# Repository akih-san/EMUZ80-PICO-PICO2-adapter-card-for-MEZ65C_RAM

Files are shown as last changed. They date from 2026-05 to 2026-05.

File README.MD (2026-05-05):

# EMUZ80 PICO/PICO2 adapter card for MEZ65C_RAM

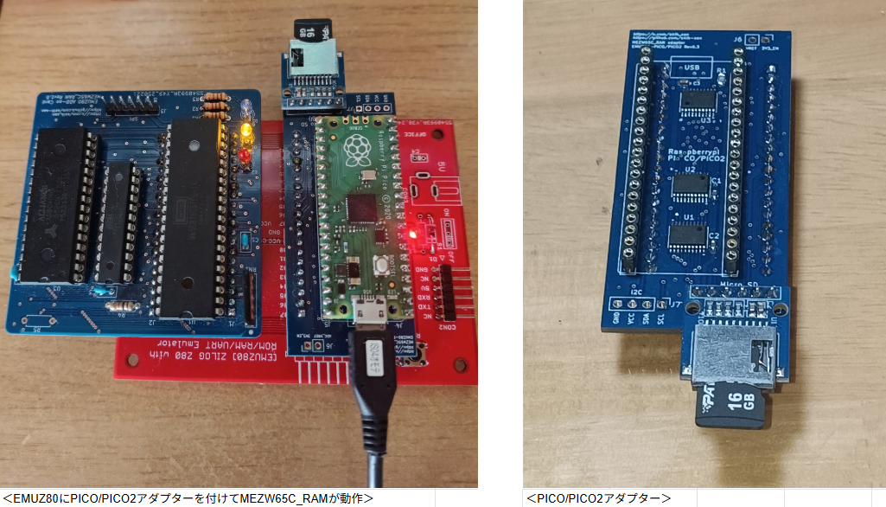
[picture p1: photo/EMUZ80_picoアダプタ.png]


電脳伝説さんの[EMUZ80](https://vintagechips.wordpress.com/2022/03/05/emuz80_reference)は、レガシーCPUをmicrochip社のPIC18F47Q43/83/84マイコンで制御しています。<br>
このマイクロコントローラーを[Raspberry Pi PICO/PICO2](https://www.raspberrypi.com/products/raspberry-pi-pico/)に置き換えて、動かせないかと考えていました。<br>
PICO/PICO2のIO数（GPIO)は、PIC18F47Q43/83/84に比べてかなり少ないため、個々のレガシーCPU専用のアダプターにする必要があります。<br>
私のお気に入りのレガシーCPUは6502なので（Z80も好きです）
[MEZW65C_RAM](https://github.com/akih-san/MEZW65C_RAM-Rev2.1G)用のアダプターを試作してみました。<br>

試作経緯については、[Ｘ（旧ツイッター）](https://x.com/akih_san/status/2036215330545213747)にアップしていますので、興味のある方はご覧ください。<br>

- [回路図](pdf/pico_pico2_to_emuz80_sch.pdf)
- [GPIO割り当て](pdf/pico_mezw65cGPIO割り当て.pdf)
- [部品表](pdf/pico_mezw65c部品表.pdf)<br>

<br>

- 電源は、USBから取るので、EMUZ80の電源は使用しない。電源回路を生かしている場合は、電源SWはOFFのままで使用すること。
- EMUZ80上のリセットSWは有効です。
- EMUZ80上のUART端子は有効ですが、PICO/PICO2のファームウェアで未対応。使用する場合は、PICOでUARTを有効にしてファームウェアを
再構築する必要があります。
- アダプタ上のI2C端子は、ファームウェア未対応です。

# 参考
FWを作成するときに、参考にしたサイトや書籍<br>

- [RP2350B EMU board](https://github.com/akih-san/RP2350B-EMU-BOARD-MEZW65C_RAM-Firmware)
- [MEZW65C_RAM-Rev2.1G](https://github.com/akih-san/MEZW65C_RAM-Rev2.1G)
- [MEZW65C_RAM-Rev2.0](https://github.com/akih-san/MEZW65C_RAM-Rev2.0)
- [MEZW65C_RAM-Rev2.1](https://github.com/akih-san/MEZW65C_RAM-Rev2.1)
- [Raspberry pi pico/pico2 The C/C++ SDK](https://www.raspberrypi.com/documentation/microcontrollers/c_sdk.html)
- [Ｃ言語を使った高精度な組み込みシステム　ラズパイPicoベアメタル開発完全ガイド](https://www.amazon.co.jp/%EF%BC%A3%E8%A8%80%E8%AA%9E%E3%82%92%E4%BD%BF%E3%81%A3%E3%81%9F%E9%AB%98%E7%B2%BE%E5%BA%A6%E3%81%AA%E7%B5%84%E3%81%BF%E8%BE%BC%E3%81%BF%E3%8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)
- PIOつくし（準備号）「Norihiro Kumagai氏](https://github.com/tendai22)
- [ちょっとTea　Time!? PICO repeating_timerの憂鬱【備忘録】](http://www.easyaudiokit.com/bekkan2025/TeaTime2025/pico_repeating_timer/timernewpage2.html)
- [Raspberry Pi Pico C/C++ インターバルタイマ割り込みを試してみる](https://qiita.com/keyyum/items/3ce448c098c546dced20)
- [Raspberry Pi PicoでPWM出力](https://rikei-tawamure.com/entry/2021/02/08/213335)
- [5V系・3.3V系信号レベル変換](https://www.cepstrum.co.jp/hobby/5v33v/5v33v.html)
- [FatFs library for Raspberry Pi Pico / Pico 2](https://github.com/elehobica/pico_fatfs)

# 謝辞
このボードを作成するに至った経緯は、[DragonBallEZ氏](https://github.com/kyo-ta04/)の[Super AKI-80の組み立て方](https://note.com/quiet_duck4046/n/n32906e1dfb96?sub_rt=share_sb)と、[Pico2ROMEmu_PCB](https://github.com/kyo-ta04/Pico2ROMEmu_PCB)がきっかけで、Raspberry pi pico/pico2に興味が湧いたことからはじまります。<br>
[Norihiro Kumagai氏](https://github.com/tendai22)の[emuz80_pico2](https://github.com/tendai22/emuz80_pico2)は非常に参考になりました。<br>
### 参考にしたサイトと共に、とても感謝しています。

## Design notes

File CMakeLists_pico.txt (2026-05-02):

# Generated Cmake Pico project file

cmake_minimum_required(VERSION 3.13)

set(CMAKE_C_STANDARD 11)
set(CMAKE_CXX_STANDARD 17)
set(CMAKE_EXPORT_COMPILE_COMMANDS ON)

# Initialise pico_sdk from installed location
# (note this can come from environment, CMake cache etc)

# == DO NOT EDIT THE FOLLOWING LINES for the Raspberry Pi Pico VS Code Extension to work ==
if(WIN32)
    set(USERHOME $ENV{USERPROFILE})
else()
    set(USERHOME $ENV{HOME})
endif()
set(sdkVersion 2.2.0)
set(toolchainVersion 14_2_Rel1)
set(picotoolVersion 2.2.0-a4)
set(picoVscode ${USERHOME}/.pico-sdk/cmake/pico-vscode.cmake)
if (EXISTS ${picoVscode})
    include(${picoVscode})
endif()
# ====================================================================================
set(PICO_BOARD pico CACHE STRING "Board type")

# Pull in Raspberry Pi Pico SDK (must be before project)
include(pico_sdk_import.cmake)

project(pico_mezw65c C CXX ASM)

add_compile_options(-O0)

# Initialise the Raspberry Pi Pico SDK
pico_sdk_init()

# Add executable. Default name is the project name, version 0.1

add_executable(pico_mezw65c pico_mezw65c.c
		io_dos.c
        fatfs/ff.c
        iodev/iodev.c
        iodev/cpu_ctl.c
        iodev/mem_ctl.c
        iodev/spi_sd.c
        iodev/pio_dev.c
        iodev/urt_dev.c
        iodev/i2c_dev.c
)

pico_set_program_name(pico_mezw65c "pico_mezw65c")
pico_set_program_version(pico_mezw65c "0.1")

# Generate PIO header
pico_generate_pio_header(pico_mezw65c ${CMAKE_CURRENT_LIST_DIR}/w65_irq.pio)

# Modify the below lines to enable/disable output over UART/USB
pico_enable_stdio_uart(pico_mezw65c 0)
pico_enable_stdio_usb(pico_mezw65c 1)

# Add the standard library to the build
target_link_libraries(pico_mezw65c
        pico_stdlib)

# Add the standard include files to the build
target_include_directories(pico_mezw65c PRIVATE
        ${CMAKE_CURRENT_LIST_DIR}
        ${CMAKE_CURRENT_SOURCE_DIR}/fatfs/
        ${CMAKE_CURRENT_SOURCE_DIR}/iodev/include/
)

# Add any user requested libraries
target_link_libraries(pico_mezw65c 
        hardware_spi
        hardware_i2c
        hardware_pio
        hardware_pwm
        )

pico_add_extra_outputs(pico_mezw65c)

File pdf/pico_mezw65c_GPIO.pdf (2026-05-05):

＜MEZW65C_RAM GPIO割り当て＞
GPIO | 名前 | PIC | ピン | GPIO | 名前 | PIC | ピン
GP0 | D0/BR0 | RB0 | J3-8, U2-2 | GP24 | - | - | -
GP1 | D1/BR1 | RB1 | J3-7,U2-3 | GP25 | LED（※） | - | at poco board
GP2 | D2/BR2 | RB2 | J3-6,U2-4 | GP26 | CLK | RA3 | J2-5
GP3 | D3/BR3 | RB3 | J3-5,U2-5 | GP27 | R/W | RA4 | J2-6
GP4 | D4/BR4 | RB4 | J3-4,U2-6 | GP28 | RDY | RA5 | J2-7
GP5 | D5/BR5 | RB5 | J3-3,U2-7 | | RUN | RE3 | J2-1
GP6 | D6/BR6 | RB6 | J3-2,U2-8 | | AL0 | RC0 | U2-19,J2-15
GP7 | D7/BR7 | RB7 | J3-1,U2-9 | | AL1 | RC1 | U2-18,J2-16
GP8 | RES | RE0 | J2-8 | | AL2 | RC2 | U2-17,J2-17
GP9 | NMI | RE1 | J2-9 | | AL3 | RC3 | U2-16,J2-18
GP10 | FF_CK | - | U1/U2-11 | | AL4 | RC4 | U2-15,J3-18
GP11 | FF_OE | - | U1/U2-1 | | AL5 | RC5 | U2-14,J3-17
GP12 | UART TX | RA6 | J2-14 | | AL6 | RC6 | U2-13,J3-16
GP13 | UART RX | RA7 | J2-13 | | AL7 | RC7 | U2-12,J3-15
GP14 | SDA | - | J7-2 | | AM0 | RD0 | U1-19,J2-19
GP15 | SCL | - | J7-1 | | AM1 | RD1 | U1-18,J2-20
GP16 | MISO | - | J1-2 | | AM2 | RD2 | U1-17,J3-20
GP17 | SPI_CS | - | J1-5 | | AM3 | RD3 | U1-16,J3-19
GP18 | SPI_CK | - | J1-3 | | AM4 | RD4 | U1-15,J3-14
GP19 | MOSI | - | J1-4 | | AM5 | RD5 | U1-14,J3-13
GP20 | BE | RA0 | J2-2 | | AM6 | RD6 | U1-13,J3-12
GP21 | DCK | RA1 | J2-3 | | AM7 | RD5 | U1-12,J3-11
GP22 | IRQ | RA2 | J2-4 | | SPI_SS | RE2 | J2-10,+5V
GP23 | - | - | -
※ GP25のLEDは、SDカードアクセス時に点滅

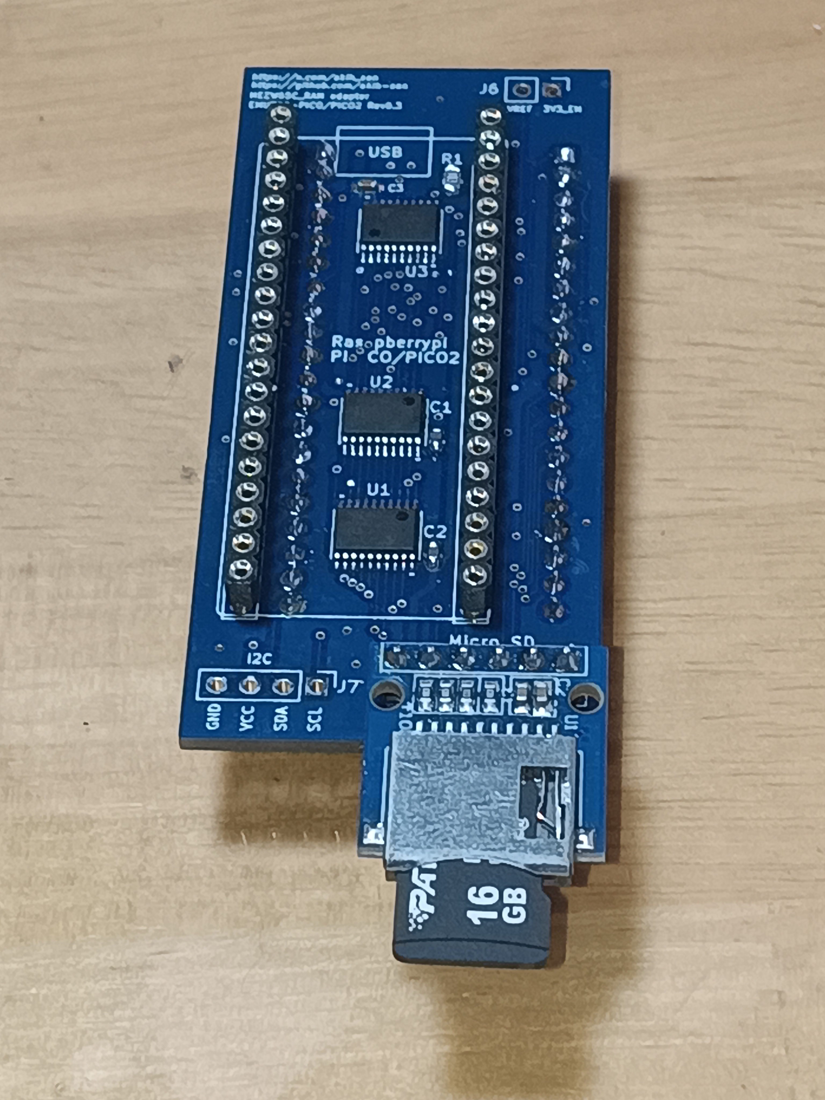
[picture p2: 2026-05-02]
photo/emuz80_pico_adapter.jpg

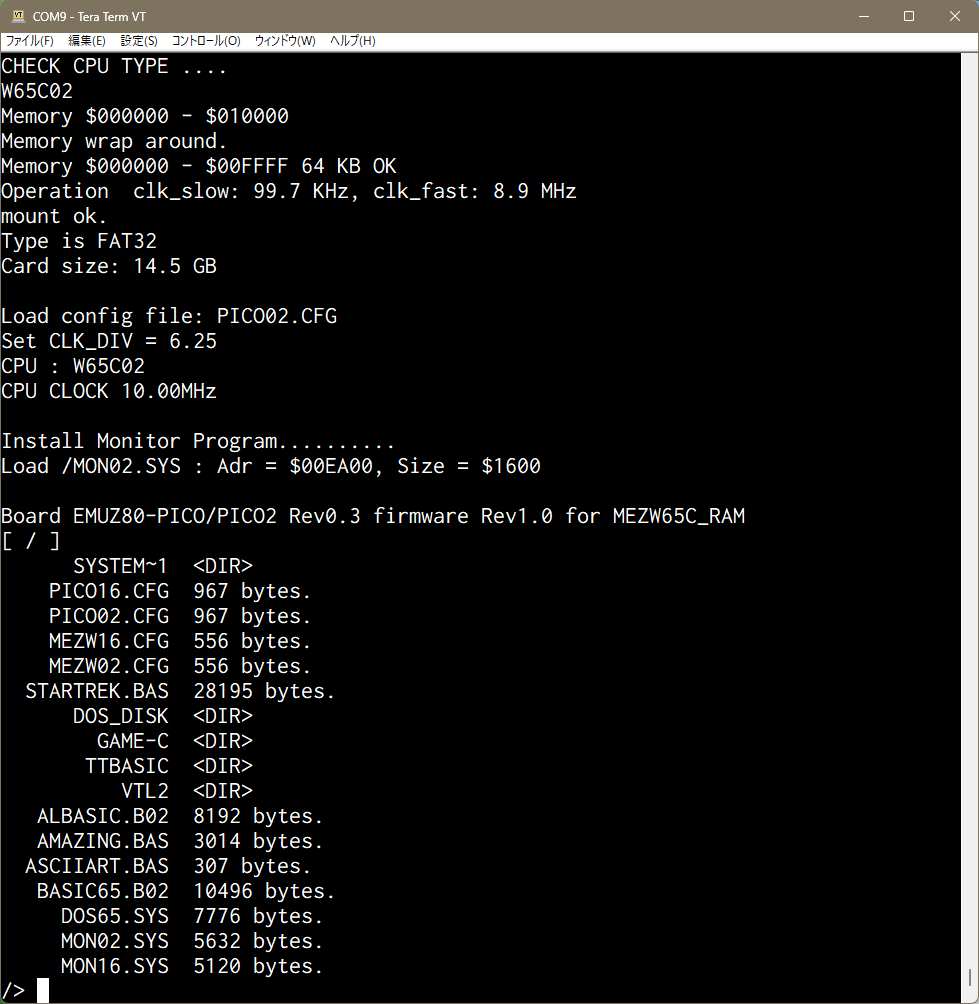
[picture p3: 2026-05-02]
photo/w65c02_opening.png

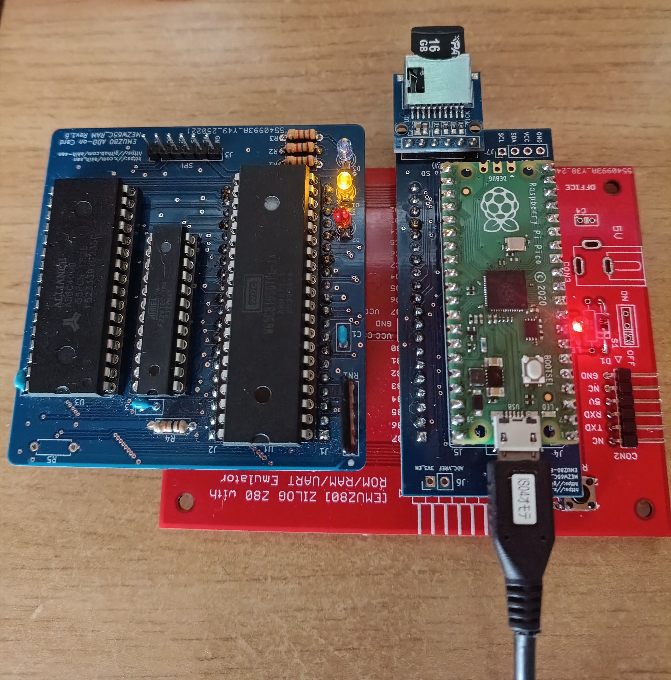
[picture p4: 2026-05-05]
photo/EMUZ80_PICO_PICO2_MEZ65C_RAM.jpg

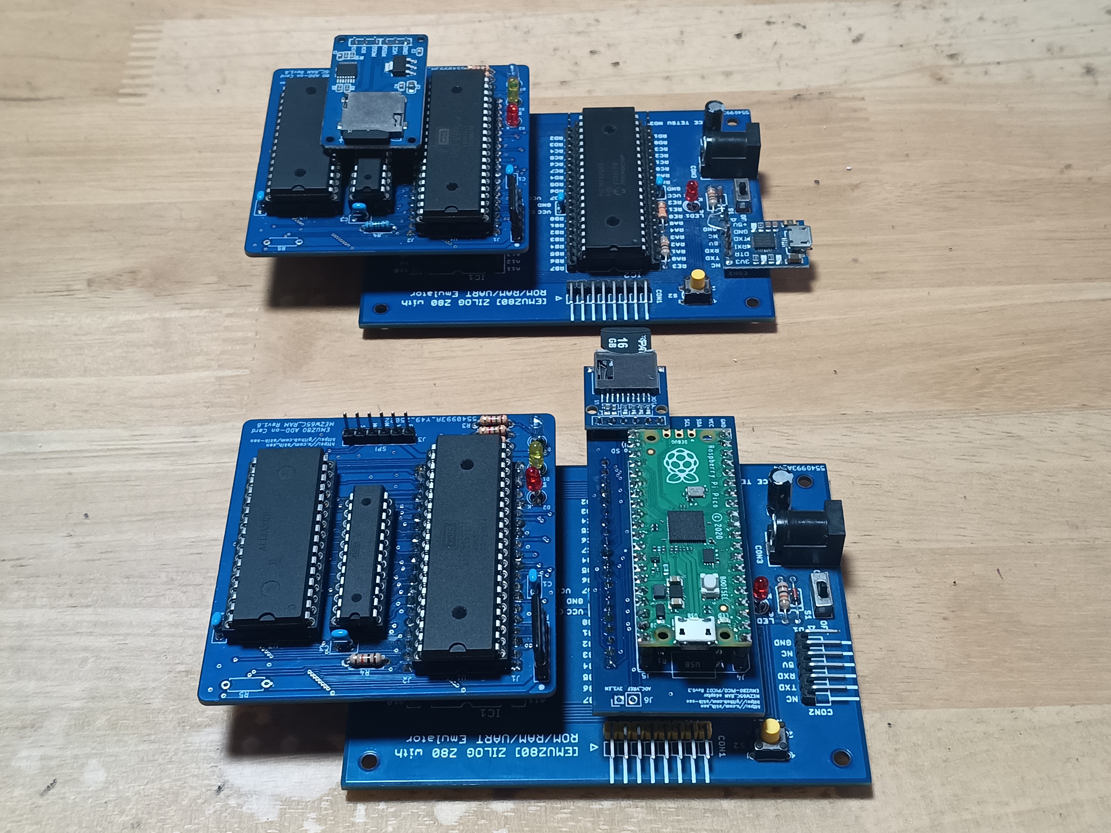
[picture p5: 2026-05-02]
photo/pico_adapter_and_PIC18F47Q43.jpg

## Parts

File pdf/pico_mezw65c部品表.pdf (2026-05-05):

MEZW65C_RAM PICO/PICO2アダプター部品表

部品番号 | 数 | 部品名 | 値 | 参考型番
C1,C2,C3 | 3 | チップ積層セラミックコンデンサー F 1608 | 0.1μF50V | GRM188F11H104ZA01（秋月電子通商）
J1 | 1 | SPI用 ピンヘッダー 1x06 2.54mm | | PH-1x6SG/RH（秋月電子通商）
J2,J3 | 2 | ピンソケット (メス) (シングル20P) 1x20 2.54mm | | FH-1x20（秋月電子通商）
JJ4,J5 | 2 | 丸ピンIC用ソケット (シングル20P) 1×20 2.54mm | | 6604S-20（秋月電子通商）
J6 | 1 | ピンヘッダー 1×2 (2P) | | PH-1X2SG（秋月電子通商）
J7 | 1 | I2C用ピンヘッダー 1x04 2.54mm | | PHA-1x4SG（秋月電子通商）
R1 | 1 | 金属皮膜チップ抵抗器 2012 | 1/8W10kΩ ±0.1% | RG2012-N-103-B-T5（秋月電子通商）
U1,U2 | 2 | IC FF D-TYPE SGL 8-BIT 20-TSSOP | 74LCX574FT | 74LCX574FT（東芝）
U3 | 1 | IC BUFF NON-INVERT 8-BIT 5.5V 20-TSSOP | 74VHCT541AFT | 74VHCT541AFT（東芝）

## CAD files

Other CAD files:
iodev/reset.obj

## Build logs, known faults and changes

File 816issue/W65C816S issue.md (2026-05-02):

# W65C816 Reset issue

開発中の「EMUZ80 PICO/PICO2 adapter card for MEZ65C_RAM」で<br>
[W65C186のリセットがかからない問題](reset_error.png)がありました。<br>
色々調べて、やっと原因が分かりました。<br>
W65C816S(5V)とPICO/PICO2を(3.3V)を直接繋いで制御していますが、<br>
W65C816SのDC特性では、Highレベルの規定が3.3V以上必要になるので
3.3V系を直接繋いでも正常に動作しないようです。<br>

DC特性でW65C816Sは、[Vih = VDD×0.8(min4.75V) ∴Vih = 3.8V](W65C816S_Vih.png)<br>
W65C02Sは、[Vih = VDD×0.7(min4.75V) ∴Vih = 3.32V](W65C02S_Vih.png)<br>
W65C02SはVihが3.32Vでギリギリ実力で動いてるようです。<br>
恐らく個体差が出ると思われます。<br>
<br>
Z80のVihは2V程度なので、3.3V系をダイレクトに繋いでも大丈夫なのでしょう。<br>

試しに電圧4.5Vにしたところ、[W65C816Sにリセットがかかり立ち上がりました。](Successful_startup.png)<br>
ただし、電圧下げているのでどこまで安定動作するか分かりません。<br>

対策としては入力信号のレベル変換ですが、Vih 2V程度のバッファIC<br>
[(74VHCT541AFT)を通したところ、リセットがかかり正常に立ち上がりました。](buffer_test.png)<br>
MEZ65C_RAM上のメモリメモリ（AS6C4008）とCPLD（ATF22V10C）とPICO/PICO2は<br>
直結しても特に問題はなさそうです。<br>

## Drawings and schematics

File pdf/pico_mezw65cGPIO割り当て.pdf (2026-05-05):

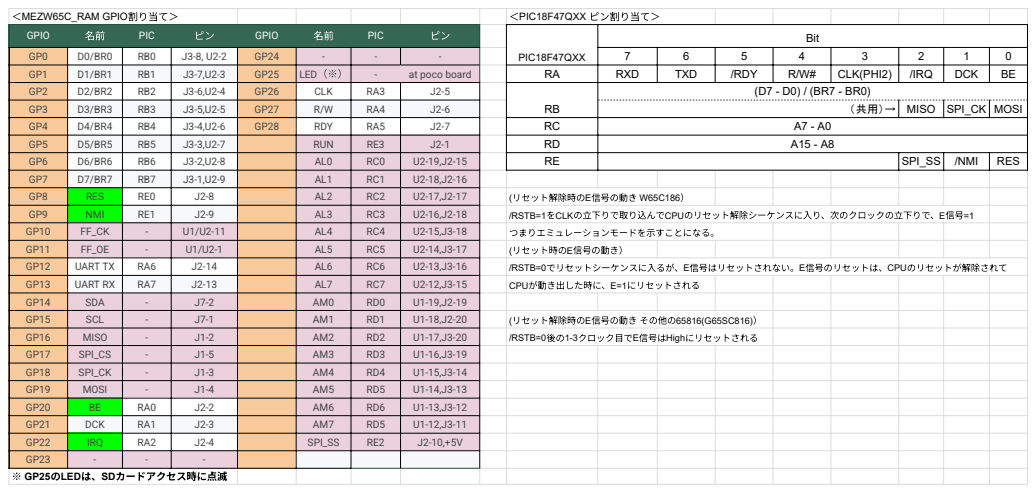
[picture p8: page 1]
MISO; SPI_CK; MOSI

＜MEZW65C_RAM GPIO割り当て＞ | | | | | | ＜PIC18F47QXX ピン割り当て＞
GPIO | 名前 | PIC | ピン | GPIO | 名前 | PIC | ピン | PIC18F47QXX | Bit
GP0 | D0/BR0 | RB0 | J3-8, U2-2 | GP24 | - | - | - | | 7 | 6 | 5 | 4 | 3 | 2 | 1 | 0
GP1 | D1/BR1 | RB1 | J3-7,U2-3 | GP25 | LED（※） | - | at poco board | RA | RXD | TXD | /RDY | R/W# | CLK(PHI2) | /IRQ | DCK | BE
GP2 | D2/BR2 | RB2 | J3-6,U2-4 | GP26 | CLK | RA3 | J2-5 | RB | (D7 - D0) / (BR7 - BR0)
GP3 | D3/BR3 | RB3 | J3-5,U2-5 | GP27 | R/W | RA4 | J2-6
GP4 | D4/BR4 | RB4 | J3-4,U2-6 | GP28 | RDY | RA5 | J2-7 | RC | A7 - A0
GP5 | D5/BR5 | RB5 | J3-3,U2-7 | | RUN | RE3 | J2-1 | RD | A15 - A8
GP6 | D6/BR6 | RB6 | J3-2,U2-8 | | AL0 | RC0 | U2-19,J2-15 | RE | | | | | | SPI_SS | /NMI | RES
GP7 | D7/BR7 | RB7 | J3-1,U2-9 | | AL1 | RC1 | U2-18,J2-16
GP8 | RES | RE0 | J2-8 | | AL2 | RC2 | U2-17,J2-17 | (リセット解除時のE信号の動き W65C186）
GP9 | NMI | RE1 | J2-9 | | AL3 | RC3 | U2-16,J2-18 | /RSTB=1をCLKの立下りで取り込んでCPUのリセット解除シーケンスに入り、次のクロックの立下りで、E信号=1
GP10 | FF_CK | - | U1/U2-11 | | AL4 | RC4 | U2-15,J3-18 | つまりエミュレーションモードを示すことになる。
GP11 | FF_OE | - | U1/U2-1 | | AL5 | RC5 | U2-14,J3-17 | (リセット時のE信号の動き）
GP12 | UART TX | RA6 | J2-14 | | AL6 | RC6 | U2-13,J3-16 | /RSTB=0でリセットシーケンスに入るが、E信号はリセットされない。E信号のリセットは、CPUのリセットが解除されて
GP13 | UART RX | RA7 | J2-13 | | AL7 | RC7 | U2-12,J3-15 | CPUが動き出した時に、E=1にリセットされる
GP14 | SDA | - | J7-2 | | AM0 | RD0 | U1-19,J2-19
GP15 | SCL | - | J7-1 | | AM1 | RD1 | U1-18,J2-20 | (リセット解除時のE信号の動き その他の65816(G65SC816)）
GP16 | MISO | - | J1-2 | | AM2 | RD2 | U1-17,J3-20 | /RSTB=0後の1-3クロック目でE信号はHighにリセットされる
GP17 | SPI_CS | - | J1-5 | | AM3 | RD3 | U1-16,J3-19
GP18 | SPI_CK | - | J1-3 | | AM4 | RD4 | U1-15,J3-14
GP19 | MOSI | - | J1-4 | | AM5 | RD5 | U1-14,J3-13
GP20 | BE | RA0 | J2-2 | | AM6 | RD6 | U1-13,J3-12
GP21 | DCK | RA1 | J2-3 | | AM7 | RD5 | U1-12,J3-11
GP22 | IRQ | RA2 | J2-4 | | SPI_SS | RE2 | J2-10,+5V
GP23 | - | - | -
※ GP25のLEDは、SDカードアクセス時に点滅

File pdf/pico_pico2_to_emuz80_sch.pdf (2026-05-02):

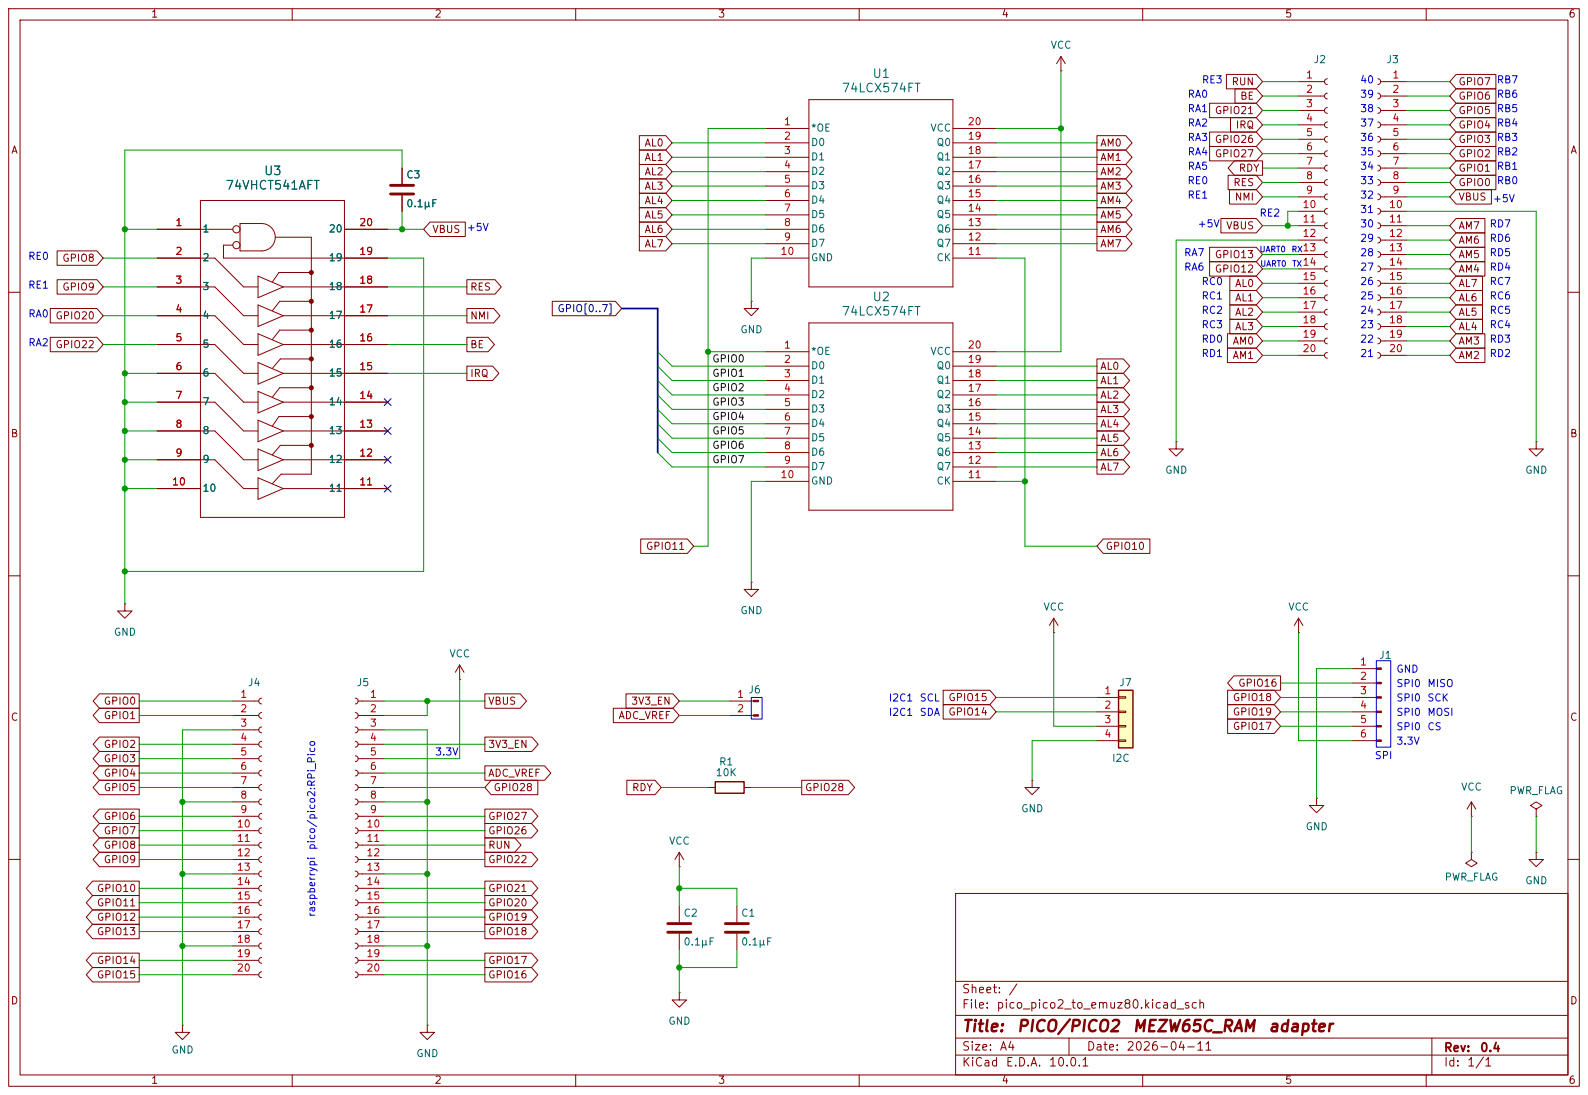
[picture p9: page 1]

Size: A4 | Rev: 0.4
KiCad E.D.A. 10.0.1 | Id: 1/1

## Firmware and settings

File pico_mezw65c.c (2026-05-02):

/* 
 *  Target: pico_mezw65c
 *  Written by Akihito Honda (Aki.h @akih_san)
 *  https://x.com/akih_san
 *  https://github.com/akih-san
 *
 * Date: 2026.03.16
; Copyright (c) 2026 Akihito Honda
;
; Released under the MIT license
;
; Permission is hereby granted, free of charge, to any person obtaining a copy of this
; software and associated documentation files (the “Software”), to deal in the Software
; without restriction, including without limitation the rights to use, copy, modify, merge,
; publish, distribute, sublicense, and/or sell copies of the Software, and to permit persons
; to whom the Software is furnished to do so, subject to the following conditions:
;
; The above copyright notice and this permission notice shall be included in all copies or
; substantial portions of the Software.
; 
; THE SOFTWARE IS PROVIDED “AS IS”, WITHOUT WARRANTY OF ANY KIND, EXPRESS
; OR IMPLIED, INCLUDING BUT NOT LIMITED TO THE WARRANTIES OF
; MERCHANTABILITY, FITNESS FOR A PARTICULAR PURPOSE AND
; NONINFRINGEMENT. IN NO EVENT SHALL THE AUTHORS OR COPYRIGHT HOLDERS
; BE LIABLE FOR ANY CLAIM, DAMAGES OR OTHER LIABILITY, WHETHER IN AN
; ACTION OF CONTRACT, TORT OR OTHERWISE, ARISING FROM, OUT OF OR IN
; CONNECTION WITH THE SOFTWARE OR THE USE OR OTHER DEALINGS IN THE
; SOFTWARE.
*/

#include <stdio.h>
#include <stdlib.h>
#include <string.h>
#include "pico/stdlib.h"
#include "hardware/spi.h"
#include "hardware/i2c.h"
#include "hardware/pio.h"
#include "hardware/uart.h"
#include "hardware/clocks.h"

#include "urt_dev.h"
#include "ff.h"
#include "pico_w65.h"
#include "pico_mezw65c.h"

///////////////////////////////////////
// global values
///////////////////////////////////////
uint8_t buffer[SECTOR_SIZE];
uint8_t	cpu_flg;				// CPU flg 0:W65C02 1:W65C816
uint8_t	wup_flg;
uint8_t	nmi_sig;
file_header fh;
drive_t drives[NUM_DRIVES];
uint8_t ctlq_ev;		// Ctrl+Q flag
uint8_t irq_flg;
uint8_t irqMask;
int maskTimer;

uint8_t cin_no;			// 0 : INPUT_UART 1 : INPUT_FILE

float clk_fs;
uint32_t bioreq_ubuffadr;
uint32_t bioreq_cbuffadr;

int (*get_char[2])(void) = {
	u_getch,
	in_file
};

unsigned int (*strin_func[2])(char *, uint8_t) = {
	get_str,
	str_inf
};

///////////////////////////////////////
// local values
///////////////////////////////////////
static FATFS fs;
static char *arg[arg_num];
static char line_buf[line_size];
static bios_inv binv;
static uint8_t mon;
static uint32_t raw_addr;
static uint8_t load_flg;
static bios_inv binv;
static uint8_t mon;
static uint16_t frd_ptr;		// read pointer : cin_file[frd_ptr]
//static uint16_t fin_cnt;
UINT fin_cnt;
//static uint16_t fin_size;
uint16_t fin_size;
static char fin_name[13];		// redirect file name
static FILINFO fileinfo;

const uint32_t PIN_LED = PICO_PIN_LED;  // GPIO25 is board LED
static bool _led = false;

#define num_param 2
static sys_param t_conf[num_param] = {
	{"CLK_DIV", &clk_fs},
	{"REQ_HDR", (float *)&bioreq_ubuffadr}	// can NOT use pico, pico2
};

#define num_com 15
static com_param cmd[num_com+1] = {
	{"LS", scan_files},
	{"DIR",scan_files1},
	{"CD",change_directory},
	{"LOAD",load_file},
	{"CSTART",restart_prog},
	{"WSTART",wstart_prog},
	{"RETI",return_cpu},
	{"REG",print_reg},
	{"MONITOR", mon_prog},
	{"MDUMP",mem_dump},
	{"SHOW",see_file},
	{"FLASH",flash_apl},
	{"DOS65",open_dos65},
	{"HELP",print_com},
	{"?",print_com},
	{"",boot_file}
};

static const char *mezID = "MEZW65C";
static char *board_name = "RP2350B EMU BORD firmware Rev1.0 for MEZW65C_RAM Rev1.6";
static const TCHAR *conf02 = "PICO02.CFG";
static const TCHAR *conf16 = "PICO16.CFG";
static char *mon02 = "/MON02.SYS";
static char *mon16 = "/MON16.SYS";

static char *dosdir	= "DOS_DISK";
static char *dos65 = "/DOS65.SYS";

static FIL files[NUM_DRIVES];
static FIL in_fl;

//
// main program
//
int main(void)
{
	int c;
	char *buf, *res;
	FRESULT rs;
	
	cin_no	= INPUT_UART;	// input console (UART)
	wup_flg = 0;	// clear wakeup flag for NMI
	nmi_sig = 0;
	fh.nmi_sw = 0;
	raw_addr = 0;
	load_flg = 0;
	binv.sw = 0;
	clk_fs = W65_CLK_DIV_2;	// default 2MHz
	cpu_flg = 0;			// start up: 6502 mode

	stdio_init_all();
	sleep_ms(1000);

    // LED off
    gpio_init(PIN_LED);
    gpio_set_dir(PIN_LED, GPIO_OUT);
    _set_led(false);

	port_init();
	setup_pio();

//#define USE_UART
	#ifdef USE_UART
	// initialize UART0
	init_uart();
	#endif

//#define USE_I2C
	#ifdef USE_I2C
	// initialize UART0
	init_i2c();
	#endif

	clk_init();				// initial CLK = 2MHz
	cpu_flg = reset_cpu();
	check_ram();			// ram check
	mount_sd_card();		// mount sd
	load_config();
	reset_clk();

	if (!cpu_flg) printf("CPU : W65C02\r\n");
	else printf("CPU : W65C816\r\n");
	printf("CPU CLOCK %2.2fMHz\r\n\n", clock_get_hz(clk_sys)/clk_fs/(WRAP_COUNT+1)/1000000);

	startIntervalTimer();
	setup_monitor();
	printf("\r\n%s\n\r", board_name);

	/* print root directory */
	arg[0] = "";
	scan_files();

	for(;;) {
		f_getcwd(&line_buf[0], line_size);
		printf("%s> ", &line_buf[0]);								/* pirnt prompt */
		for(c = 0; c < arg_num; c++) arg[c] = 0;

		if (!get_line(&line_buf[0], line_size)) continue;			/* console input */
		/* search command */
		for( c=0;  c < num_com; c++ ) {
			if ((res = strstr(&line_buf[0], cmd[c].cmd_name ))) {
				buf = (char *)(res+strlen(cmd[c].cmd_name));		/* buf = next point */
				set_arg(buf);
				break;
			}
		}
		// do command operation

		if ( c == num_com ) set_arg(&line_buf[0]);
		rs = (*cmd[c].func)();								/* call cmd function */

		if( rs == (FRESULT)-2 ) printf("\r\nAssert NMI interrupt.\r\n");
		else if ( rs != FR_OK ) printf("Invalid( command | file | directory )\r\n");
	}

}

static void _set_led(bool flag)
{
    gpio_put(PIN_LED, flag);
    _led = flag;
}

void stop_fw(int count)
{
	printf("Stop Firmware(%d)\n\r", count);
    while (true) {
        for (int i = 0; i < count; i++) {
            _set_led(true);
            sleep_ms(250);
            _set_led(false);
            sleep_ms(250);
        }
        _set_led(false);
        sleep_ms(500);
    }
}

//
// mount SD card
//
static void mount_sd_card(void) {

    FRESULT fr;     /* FatFs return code */

	for (int i = 0; i < 5; i++) {   
        fr = f_mount(&fs, "", 1);
        if (fr == FR_OK) break;
        printf("mount error fr(%d) -> retry\r\n", fr);
        pico_fatfs_reboot_spi();
    }
    if (fr != FR_OK) {
        printf("mount error fr(%d) -> retry\r\n", fr);
        stop_fw(MOUNT_SD_CARD_ERROR);		// halt!
    }
    printf("Operation  clk_slow: %3.1f KHz, clk_fast: %2.1f MHz\r\n",
        (float)pico_fatfs_get_clk_slow_freq() / 1000,
        (float)pico_fatfs_get_clk_fast_freq() / 1000000);
    printf("mount ok.\r\n");

    switch (fs.fs_type) {
        case FS_FAT12:
            printf("Type is FAT12\r\n");
            break;
        case FS_FAT16:
            printf("Type is FAT16\r\n");
            break;
        case FS_FAT32:
            printf("Type is FAT32\r\n");
            break;
        default:
            printf("Type is unknown\r\n");
	        stop_fw(MOUNT_SD_CARD_ERROR);		// halt!
    }
//    2097152 =  (1024 * 1024 * 1024) / 512    1Gbytes = 1024 * 1024 * 1024
    printf("Card size: %2.1f GB\r\n", (float)(fs.csize * fs.n_fatent) / 2097152);
}

static uint8_t del_space(char *bytes) {
	uint8_t pos = 0;
	uint8_t i = 0;
	char c;
	
	while( (c = bytes[i++]) ) {
		if (c == '\r' || c == '\n' || c == ' ') {
			continue;
		}
		bytes[pos++] = c;
	}
	bytes[pos] = c;		// save NULL code
	return pos;
}

static int get_line(char *s, int length) {
	char n;
	int c;
	
	for (c=0;;) {
		n = (char)u_getch();
		if ( n == BS ) {
			if ( c > 0) {
				putchar(BS);
				putchar(' ');
				putchar(BS);
				c--;
				s--;
			}
			continue;
		}
		if ( n == CR || n == LF ) {
			*s = 0x00;
			printf("\r\n");
			break;
		}
		if ( n < SPACE ) continue;
		if ( c <= length-1 ) {
			putchar(n);
			if ( n >='a' && n <='z' ) n -= 0x20;		// lower to upper
			*s++ = n;
			c++;
		}
	}
	return c;
}

static FRESULT scan_files(void) {
	FRESULT res;
	FILINFO fno;
	FIL fl;
	DIR dir;
	char *fn;

	res = f_opendir(&dir, arg[0]);
	if (res == FR_OK) {		// directory
		f_getcwd( &buffer[0], SZ_STR);
		// print directory name
		if ( *arg[0] == '\0' ) {	//open current directory
			printf("[ %s ]\r\n", &buffer[0] );
		}
		else { // open directory specified strings with arg[0]
			if ( !buffer[1] ) { //current directory is root directory
				printf("[ /%s ]\r\n", arg[0] );
			}
			else { //current directory is NOT root directory
				printf("[ %s/%s ]\r\n", &buffer[0], arg[0] );
			}
		}
		// print files
		for (;;) {
			res = f_readdir(&dir, &fno);
			if (res != FR_OK || fno.fname[0] == 0) break;
			if (fno.fname[0] == '.') continue;				/* ignore '.'  */
			fn = fno.fname;
			if (fno.fattrib & AM_DIR) {					/* Directory */
				printf("  %12s\t<DIR>\r\n", fno.fname);
			}
			else {									/* file */
				printf("  %12s\t%ld bytes.\r\n", fn, fno.fsize);
			}
		}
		f_closedir(&dir);
	}
	else {
		if (res == FR_NO_PATH) { // check file
			res = f_open(&fl, (const TCHAR *)arg[0], FA_READ);
			if ( res == FR_OK ) {
				printf("  %12s\t%ld bytes.\r\n", arg[0], f_size(&fl));
				f_close( &fl );
			}
		}
	}
	return res;
}

static FRESULT scan_files1(void) {
	FRESULT res;
	FILINFO fno;
	FIL fl;
	uint8_t	fcnt;
	char *fn, *path;
	DIR dir;

	path = arg[0];
	fcnt = 0;
	
	res = f_opendir(&dir, path);
	if (res == FR_OK) {		// directory
		f_getcwd(&buffer[0], SZ_STR);
		// print directory name
		if ( *path == '\0' ) printf("[ %s ]\r\n", &buffer[0] );
		else if ( !(buffer[1]) ) printf("[ /%s ]\r\n", path );
		else printf("[ %s/%s ]\r\n", &buffer[0], path );

		// print files
		for (;;) {
			res = f_readdir(&dir, &fno);
			if (res != FR_OK || fno.fname[0] == 0) {
				if ( fcnt ) {
					printf("\r\n");
					break;
				}
			}
			if (fno.fname[0] == '.') continue;				/* ignore '.'  */
			fn = fno.fname;
			if (fno.fattrib & AM_DIR) {					/* Directory */
				printf("[%12s] ", fn);
			}
			else {									/* file */
				printf(" %12s  ", fn);
			}
			fcnt += 1;
			if (fcnt == 5 ) {
				printf("\r\n");
				fcnt = 0;
			}
		}
		f_closedir(&dir);
	}
	else {
		if (res == FR_NO_PATH) { // check file
			res = f_open(&fl, (const TCHAR *)path, FA_READ);
			if ( res == FR_OK ) {
				printf("  %12s\t%ld bytes.\r\n", path, f_size(&fl));
				f_close( &fl );
			}
		}
	}
	return res;
}

static void set_arg(char *buf) {

	int i;
	
	i=0;
	while( i < arg_num ) {
		while( *buf == ' ' ) buf++;
		arg[i] = buf;
		if ( !*buf ) break;
		while( *buf && *buf != ' ' ) buf++;
		if ( !*buf ) break;
		if ( *buf == ' ' ) *buf++ = 0;
		i++;
	}
}

static FRESULT change_directory(void) { return(f_chdir( arg[0] )); } 

static FRESULT print_com(void) { 
	
	printf("\r\n<< MEZW65C_RAM Firmware Built-in command >>\r\n");
	printf("  DOS65  (Key CTL+T : terminate DOS65)\r\n");
	printf("  LS | DIR [file name | directory name\r\n");
	printf("  CD [directory name]\n\r");
	printf("  LOAD [L=load address(Hex)] file name\r\n");
	printf("  MDUMP address(Hex)\r\n");
	printf("  MONITOR [W]\r\n");
	printf("  CSTART\r\n");
	printf("  WSTART\r\n");
	printf("  RETI\r\n");
	printf("  REG\r\n");
	printf("  SHOW file name\r\n");
	printf("  FLASH\r\n");
	printf("  HELP | ?\r\n");
	return FR_OK;
}

static uint32_t get_hex(char *buf) {

	uint32_t hexval;
	char ch;
	uint32_t d;
	int c;
	
	hexval = 0;
	c = 0;
	while( *buf ) {
		ch = *buf++;
		if (ch >= 'A' && ch <= 'F') d = (uint32_t)(ch-'A'+10);
		else if (ch >= '0' && ch <= '9') d = (uint32_t)(ch-'0');
		else break;
		hexval = hexval*16 + d;
		if (++c == 8) break;
	}
	return hexval;
}

//
// setup monitor at starting MESW65C_RAM
//
static void setup_monitor(void) {

	int	rs;
	uint8_t dat;
	
	printf("Install Monitor Program..........\r\n");

	if (cpu_flg) {
		arg[0] = mon16;
		mon = 1;
	}
	else {
		arg[0] = mon02;
		mon = 0;
	}
	rs = load_program((uint8_t *)arg[0]);
	if ( rs ) stop_fw(SETUP_MONITOR_ERROR);

	//
	// Start CPU
	//
//test
//	gpio_put(46, 0);
//	sleep_us(1);
//	gpio_put(46, 1);
//test
	start_cpu();
	drive_cpu();
	return;
}

//
// load program from SD card
//
static int load_program(uint8_t *fname) {
	
	FRESULT	fr;
	FIL fl;
	uint16_t file_size;
	
	UINT	btr, br;
	uint16_t	cnt;
	uint32_t	adr, adr0;
	file_header *header;
	
	header = (file_header *)&buffer[0];

	fr = f_open(&fl, (TCHAR *)fname, FA_READ);
	if ( fr != FR_OK ) {
		printf("File Open Error.\r\n");
		return((int)fr);
	}
	adr = 0;
	cnt = file_size = (uint16_t)f_size(&fl);				// get file size
	btr = SECTOR_SIZE;										// default 512byte
	while( cnt ) {
		fr = f_read(&fl, (void *)&buffer[0], btr, &br);
		if (fr == FR_OK) {
			if ( !adr ) {		// if read sector is 1st sector then ...
				if ( raw_addr ) {	// if specified load address by raw_addr then ...
					adr = adr0 = raw_addr;
				}
				else {
					if (!strstr((const char *)header->mezID, mezID)) {	//check MEZW65C_RAM file ID
						printf("Invalid MEZW65C file.\r\n");
						fr = FR_INVALID_OBJECT;
						break;
					}
					if (header->sw_816==1 && !cpu_flg) {
						printf("Work on only W65C816..\r\n");
						fr = FR_INVALID_OBJECT;
						break;
					}
					adr = adr0 = header->load_p;
					if (!load_flg) {
						if ( header->bios_sw == 1 ) {	// file is user program
							binv.sw = header->bios_sw;
							binv.caddr = header->cstart_addr;
							binv.waddr = header->wstart_addr;
							binv.dp = header->direct_page;			//direct page
							binv.pbnk = header->op1;				//program bank
							binv.dbnk = header->op2;				//data bank
							binv.sw_816 = header->sw_816;
							sprintf((char *)binv.fname, "%s", fname);
						}
						else {
							// copy file header */
							fh.bios_sw = header->bios_sw;
							fh.load_p = header->load_p;
							fh.sw_816 = header->sw_816;
							fh.cstart_addr = header->cstart_addr;
							fh.wstart_addr = header->wstart_addr;
							fh.picif_p = header->picif_p;
							fh.irq_sw = header->irq_sw;
							fh.reg_tblp = header->reg_tblp;
							fh.reg_tsize = header->reg_tsize;
							fh.nmi_sw = header->nmi_sw;
							/* PIC common memory address */
							bioreq_ubuffadr = fh.picif_p;
							bioreq_cbuffadr = bioreq_ubuffadr + 2;
							if ( !fh.bios_sw ) binv.sw = 0;		// standalone(clear bios call flag)
						}
					}
				}
			}
			write_sram(adr, &buffer[0], (unsigned int)br);
			adr += (uint32_t)br;
			cnt -= (uint16_t)br;
			if (btr > (UINT)cnt) btr = (UINT)cnt;
		}
		else break;
	}
	if (fr == FR_OK) {
		printf("Load %s : Adr = $%06lX, Size = $%04X\r\n", fname, adr0, file_size);
	}
	else {
		if (fr != FR_INVALID_OBJECT) printf("File Load Error.\r\n");
	}
	f_close(&fl);
	return((int)fr);
}

//
// mount SD card
//
static int disk_init(void)
{
    if (f_mount(&fs, "0://", 1) != FR_OK) {
        printf("Failed to mount SD Card.\n\r");
        return -2;
    }

    return 0;
}

static void load_config(void)
{
	FIL fl;
	FRESULT	fr;
	char *buf, *dummy;
	const TCHAR *conf;
	uint16_t cnt, size;
	uint16_t adr;
	int i;
	TCHAR *str;
	float a, *vari;
	
	str = (TCHAR *)&buffer[0];
	conf = ( cpu_flg ) ? conf16 : conf02;
	
	printf("\r\nLoad config file: %s\r\n",(const char *)conf);
	
	fr = f_open(&fl, conf, FA_READ);
	if ( fr != FR_OK ) {
		printf("%s not found!\r\n", conf);
		return;
	}

	while ( f_gets(str, 80, &fl) ) {	// max 80 characters
		// delete space
		del_space(str);
		if (str[0] == ';' || str[0] == 0 ) continue;

		// search keywoard
		for( i=0; i<num_param; i++ ) {
			if (!strstr(str, t_conf[i].conf)) continue;
			if (str[strlen(t_conf[i].conf)] != '=') continue;
			// get value
			
			vari = t_conf[i].val;
			buf = &str[strlen(t_conf[i].conf)+1];			// get address of value string
			a = (float)strtof((const char *)buf, &dummy);	// get value

			if (!a) printf("Error! Illegal Formatting value!!\r\n");
			else *vari = a;		// set value

			printf("Set %s = %2.2f\r\n", (const char *)t_conf[i].conf, *vari);
		}
	}
	if (!f_eof(&fl)) {
		printf("CONFIG KEY NOT FOUND!\r\n");
	}
	f_close( &fl );
	return;
}

static FRESULT drive_cpu(void) { 

	FRESULT rs;

	ctlq_ev = 0;	// clear Ctrl+Q key flag
	nmi_sig = 0;
	irq_flg = 0;

	if( !fh.irq_sw ) irqMask = 1;
	else irqMask = 0;
	board_event_loop();
	
	// wup_flg = 0xFF : NMI, wup_flg = 1 : sleep( or terminate )
	rs = (FRESULT)(wup_flg - 1);		// get wakeup reason -2:NMI 
	wup_flg = 0;						// clear wakeup flag for NMI

	return rs;
}

static void prt_reload(void) { 
	printf("Reload monitor %s\r\n", arg[0]);
}

static FRESULT boot_file(void) { 

	FRESULT rs;
	uint8_t flag, m;
	UINT cnt;
	
	if ( strstr((const char *)arg[0], mon02+1) ) m = 0;
	else if ( strstr((const char *)arg[0], mon16+1) ) m = 1;
	else m = 2;
	if ( m != 2) {
		mon = m;
		prt_reload();
		binv.sw = 0;	//clear user program
		rs = (FRESULT)load_program((uint8_t *)arg[0]);
		if ( rs ) return 0;

		start_cpu();
		rs = drive_cpu();
		return rs;
	}
	
	// check mark '<' for FILE INPUT modde
	if ( *arg[1] == '<' ) {
		sprintf(&fin_name[0], "%s", arg[2]);
		fin_cnt = 0xffff;	// set open flag
		cin_no = INPUT_FILE;								// change console input UART to FILE
	}

	//check DOS65.SYS
	if ( strstr((const char *)arg[0], dos65+1) ) {
		rs = open_dos65();
		return rs;
	}
	
	flag = 0;
	printf("Flie(%s) loading...\r\n", arg[0]);
	
	rs = (FRESULT)load_program((uint8_t *)arg[0]);
	if ( rs ) return 0;

	if ( binv.sw ) {	// user program
		if ( cpu_flg ) {	// 65816
			if ( mon ) {	//mon16
				if ( !binv.sw_816 ) {
					arg[0] = mon02;
					mon = 0;
					flag = 1;
					printf("Reload %s for Emulation Mode...\r\n", arg[0]);
				}
			}
			else {	// mon02
				if ( binv.sw_816 ) {
					arg[0] = mon16;
					mon = 1;
					flag = 1;
					printf("Reload %s for Native Mode...\r\n", arg[0]);
				}
			}
			if ( flag ) {	// reroad monitor
				rs = (FRESULT)load_program((uint8_t *)arg[0]);
				if ( rs ) return 0;
			}
		}
		binv.addr = binv.caddr;
		write_sram( fh.load_p+mezID_off, (uint8_t *)&binv, BINV_SIZE );		// address of monitor's mezID
	}

	write_sram(0xFFFC, (uint8_t *)&fh.cstart_addr, 2);
	start_cpu();	//set monitor cold start
	rs = drive_cpu();
	if ( !rs ) {
		if ( !fh.bios_sw ) {	// if standalone prpgram is terminated, then need reload monitor
			if (cpu_flg) {
				arg[0] = mon16;
				mon = 1;
			}
			else {
				arg[0] = mon02;
				mon = 0;
			}
			prt_reload();
			rs = (FRESULT)load_program((uint8_t *)arg[0]);
			if ( rs ) return 0;
			start_cpu();
			rs = drive_cpu();
		}
		binv.sw = 0;	// terminate bios_call program
	}
	return rs;
}

static FRESULT return_cpu(void) { 
	
	FRESULT rs;

	continue_action();
	rs = drive_cpu();
	return rs;
}

static FRESULT print_reg(void) { 
	reg816 *reg_816;
	reg02 *reg_02;

	read_sram((uint32_t)fh.reg_tblp, &buffer[0], (unsigned int)fh.reg_tsize);

	if (fh.sw_816) {	/* 65816 */
		reg_816 = (reg816 *)&buffer[0];
		printf("A=$%04X X=$%04X Y=$%04X SP=$%04X PC=$%04X PSR=$%02X\r\n",
				reg_816->REGA, reg_816->REGX,reg_816->REGY,reg_816->REGSP,reg_816->REGPC,reg_816->REGPSR);
		printf("PBR=$%02X DBR=$%02X DPR=$%04X\r\n",reg_816->REGPB, reg_816->REGDB, reg_816->REGDP);
	}
	else {
		reg_02 = (reg02 *)&buffer[0];
		printf("A=$%02X X=$%02X Y=$%02X SP=$01%02X PC=$%04X PSR=$%02X\r\n",
				reg_02->REGA, reg_02->REGX,reg_02->REGY,reg_02->REGSP,reg_02->REGPC,reg_02->REGPSR);
	}
	return FR_OK;
}

static FRESULT load_file(void) {
	char *p;
	
	load_flg = 1;
	if ((p = strstr(arg[0], "L=" ))) {
		raw_addr = get_hex((char *)(p+2));
		load_program((uint8_t *)arg[1]);
	}
	else {
		raw_addr = 0;
		load_program((uint8_t *)arg[0]);
	}
	load_flg = 0;
	raw_addr = 0;
	return FR_OK;
}

static FRESULT wstart_prog(void) {
	FRESULT rs;

	rs = FR_NO_FILE;
	if ( binv.sw == 1) {
		binv.addr = binv.waddr;
		write_sram( fh.load_p+mezID_off, (uint8_t *)&binv, BINV_SIZE );		// address of monitor's mezID
		
		write_sram(0xFFFC, (uint8_t *)&fh.cstart_addr, 2);
		start_cpu();
		rs = drive_cpu();
	}
	return rs;
}

static FRESULT restart_prog(void) {
	FRESULT rs;

	rs = FR_NO_FILE;
	if ( binv.sw ==1 ) {
		binv.addr = binv.caddr;
		write_sram( fh.load_p+mezID_off, (uint8_t *)&binv, BINV_SIZE );		// address of monitor's mezID

		write_sram(0xFFFC, (uint8_t *)&fh.cstart_addr, 2);
		start_cpu();
		rs = drive_cpu();
	}
	return rs;
}

static FRESULT mon_prog(void) {
	FRESULT rs;
	char *p;
	uint8_t	sw;
	
	rs = FR_OK;

	sw = 0;					// monitor wakeup signal
	write_sram( fh.load_p+mezID_off, &sw, 1 );			// address of  fh.mezID

	if ((p = strstr(arg[0], "W" ))) write_sram(0xFFFC, (uint8_t *)&fh.wstart_addr, 2);
	else write_sram(0xFFFC, (uint8_t *)&fh.cstart_addr, 2);

	start_cpu();
	rs = drive_cpu();
	printf("\r\n");
	return rs;
}

static FRESULT mem_dump(void) {

	uint32_t addr;
	char *p;

	p = arg[0];
	addr = get_hex( p );

	read_sram(addr, &buffer[0], SZ_STR);		//128 bytes read memory
	util_addrdump("Mem ", addr, (const void *)&buffer[0], SZ_STR);
	return FR_OK;
}
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

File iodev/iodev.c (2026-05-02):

/* 
 *  Target: pico_mezw65c
 *  Written by Akihito Honda (Aki.h @akih_san)
 *  https://x.com/akih_san
 *  https://github.com/akih-san
 *
 * Date: 2026.03.16
; Copyright (c) 2026 Akihito Honda
;
; Released under the MIT license
;
; Permission is hereby granted, free of charge, to any person obtaining a copy of this
; software and associated documentation files (the “Software”), to deal in the Software
; without restriction, including without limitation the rights to use, copy, modify, merge,
; publish, distribute, sublicense, and/or sell copies of the Software, and to permit persons
; to whom the Software is furnished to do so, subject to the following conditions:
;
; The above copyright notice and this permission notice shall be included in all copies or
; substantial portions of the Software.
; 
; THE SOFTWARE IS PROVIDED “AS IS”, WITHOUT WARRANTY OF ANY KIND, EXPRESS
; OR IMPLIED, INCLUDING BUT NOT LIMITED TO THE WARRANTIES OF
; MERCHANTABILITY, FITNESS FOR A PARTICULAR PURPOSE AND
; NONINFRINGEMENT. IN NO EVENT SHALL THE AUTHORS OR COPYRIGHT HOLDERS
; BE LIABLE FOR ANY CLAIM, DAMAGES OR OTHER LIABILITY, WHETHER IN AN
; ACTION OF CONTRACT, TORT OR OTHERWISE, ARISING FROM, OUT OF OR IN
; CONNECTION WITH THE SOFTWARE OR THE USE OR OTHER DEALINGS IN THE
; SOFTWARE.
*/

#include <stdio.h>
#include "hardware/pwm.h"
#include "hardware/gpio.h"
#include "hardware/timer.h"
#include "hardware/sync.h"
#include "pico/stdlib.h"
#include "hardware/clocks.h"

#include "pico_w65.h"
#include "iodev.h"

static unsigned char rx_buf[URT_BUF_SIZE];
unsigned int rx_wp, rx_rp, rx_cnt;

static repeating_timer_t timer;

void port_init(void) {
	
	uint i;
	// <set GPIO direction>
	//output
	// W65_CLK  GP26	: pwm
	// W65_DCK  GP21
	// W65_BE   GP20
	// W65_IRQ  GP22	: PIO
	// W65_RW   GP27
	// W65_NMI  GP9
	// W65_RES  GP8
	// DBUS(0 - 7) GP0 - GP7
	//input
	// W65_RDY  GP28
	// IRQ is controled by PIO
	
	// pull up
//	gpio_pull_up(W65_BE);
//	gpio_pull_up(W65_RDY);

	gpio_pull_up(W65_DCK);
	gpio_pull_up(W65_IRQ);
	gpio_pull_up(W65_RW);
	gpio_pull_up(W65_NMI);
	
	gpio_set_dir(FF_CK, GPIO_OUT);
	gpio_set_dir(FF_OE, GPIO_OUT);
	gpio_set_dir(W65_RDY, GPIO_IN);
	gpio_set_dir(W65_RW, GPIO_OUT);
	gpio_set_dir(W65_DCK, GPIO_OUT);
	gpio_set_dir(W65_BE, GPIO_OUT);
	gpio_set_dir(W65_NMI, GPIO_OUT);
	gpio_set_dir(W65_RES, GPIO_OUT);
	gpio_set_dir_masked(W65_DTBS, DBUS_DIR_OUT);

	// set SIO 
	gpio_set_function(FF_CK, GPIO_FUNC_SIO);
	gpio_set_function(FF_OE, GPIO_FUNC_SIO);
	gpio_set_function(W65_DCK, GPIO_FUNC_SIO);
	gpio_set_function(W65_RDY, GPIO_FUNC_SIO);
	gpio_set_function(W65_BE, GPIO_FUNC_SIO);
	gpio_set_function(W65_RW, GPIO_FUNC_SIO);
	gpio_set_function(W65_NMI, GPIO_FUNC_SIO);
	gpio_set_function(W65_RES, GPIO_FUNC_SIO);
	for(i=W65_DBUS; i<W65_DBUS+DBUS_WIDTH; i++) gpio_set_function(i, GPIO_FUNC_SIO);

	// reset CPU
	gpio_put(W65_BE, 0);
	gpio_put(W65_RES, 0);				// RES=0 : CPU reset

	// set default value
	gpio_put(FF_OE, 0);		// active output enable
	gpio_put(FF_CK, 0);
	gpio_put(W65_DCK, 0);
	gpio_put(W65_RW, 1);
	gpio_put(W65_NMI, 1);

	gpio_put_masked(W65_DTBS, 0x00);		// set data bus = 0

	ctlq_ev = 0;

	// initialize address FF
	set_address( 0 );				// initial A0-A15 = 0
}

static int slice_num;

// initial clock 2MHz
void clk_init(void)
{
	gpio_set_function(W65_CLK,GPIO_FUNC_PWM );

	slice_num = pwm_gpio_to_slice_num(W65_CLK);		//get slice number of W65_CLK(GPIO 20 PIN)
	// set division rate
	pwm_set_clkdiv(slice_num, W65_CLK_DIV_2);
	clk_fs = W65_CLK_DIV_2;		// set default value for 2MHz
	// set wrap cout
	pwm_set_wrap(slice_num, WRAP_COUNT);
	// set pwm count
	pwm_set_chan_level(slice_num, PWM_CHAN_A, WRAP_COUNT);
	// start pwm
	pwm_set_enabled(slice_num, true);
	printf("Assert %2.2fMHz for TEST CLOCK\r\n", clock_get_hz(clk_sys)/clk_fs/(WRAP_COUNT+1)/1000000);
}

// Set cpu clock. clk_fs is set from PICO02.CFG/PICO16.CFG setting file
void reset_clk(void)
{
	// stop pwm
	pwm_set_enabled(slice_num, false);

	// set division rate
	pwm_set_clkdiv(slice_num, clk_fs);
	// set wrap cout
	pwm_set_wrap(slice_num, WRAP_COUNT);
	// set pwm count
	pwm_set_chan_level(slice_num, PWM_CHAN_A, WRAP_COUNT);
	// start pwm
	pwm_set_enabled(slice_num, true);
	
}

////////////////////////////////////////////
//
// 5ms intervel timer handler
//
////////////////////////////////////////////
bool timer_callback( repeating_timer_t *rt )
{
	int rx_data;

	// get key
	rx_data =  stdio_getchar_timeout_us (0);
	if (rx_data != PICO_ERROR_TIMEOUT) {
		// check NMI
		if ( ctlq_ev == CTL_Q && rx_data == CTL_Q) {
			ctlq_ev = 0;
			nmi_sig = 1;
			return(true);
		}
		else ctlq_ev = (uint8_t)rx_data;
		if (rx_cnt < URT_BUF_SIZE) {
			rx_buf[rx_wp] = rx_data;
			rx_wp = (rx_wp + 1) & (URT_BUF_SIZE - 1);
			rx_cnt++;
		}
	}
	if (maskTimer) return(true);
	if (!irqMask) irq_flg = 1;
	return (true);
}

// Stop 5ms intervel timer handler
//void stopIntervalTimer(void) {
//	cancel_repeating_timer(&timer);
//	timerAction_off();
//	maskTimer = 1;
//}

// Start 5ms intervel timer handler
void startIntervalTimer(void) {
	maskTimer = 1;
	irq_flg = 0;
	nmi_sig = 0;
	ctlq_ev = 0;
	add_repeating_timer_ms( -5, &timer_callback, NULL, &timer );
}

static uint32_t status;

// UART3 Recive( user side )
int u_getch(void) {
	char c;

	while(!rx_cnt);
	status = save_and_disable_interrupts();
	c = rx_buf[rx_rp];
	rx_rp = (rx_rp + 1) & ( URT_BUF_SIZE - 1);
	rx_cnt--;
	restore_interrupts(status);

	return c;               // Read data
}

unsigned int get_str(char *buf, uint8_t cnt) {
	unsigned int c, i;
	
	i = ( (unsigned int)cnt > rx_cnt ) ? rx_cnt : (unsigned int)cnt;
	c = i;
	status = save_and_disable_interrupts();
	while(i--) {
		*buf++ = rx_buf[rx_rp];
		rx_rp = (rx_rp + 1) & ( URT_BUF_SIZE - 1);
		rx_cnt--;
	}
	restore_interrupts(status);

	return c;
}
